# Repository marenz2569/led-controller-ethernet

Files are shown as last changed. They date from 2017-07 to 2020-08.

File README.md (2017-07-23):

# led-controller-ethernet

led-controller-ethernet is the hardware to the [avr-ethernet-licht firmware](https://github.com/marenz2569/avr-ethernet-licht).

Its purpurse is to control ws2812 protocol compatible leds via a [udp protocol](https://chch.it/Fensterbogenbeleuchtung).

In addition to the pcb the hardware uses an arduino pro mini and an enc28j60 breakout board.

## flexibilty

input voltage | output voltage | bridges | notes
--- | --- | --- | ---
12-36V | 12-36V | JP1 |
12-36V | 5V | JP2 |
5V | 5V | JP1 and JP2 | do not populate voltage regulator

## todo
- test if regulator may be populated when inserting 5 Volts to V\_in and bridging JP1 and JP2
- add option for rgb leds with 3 mosfets.

## license
see lgplv2.1 in LICENSE file.

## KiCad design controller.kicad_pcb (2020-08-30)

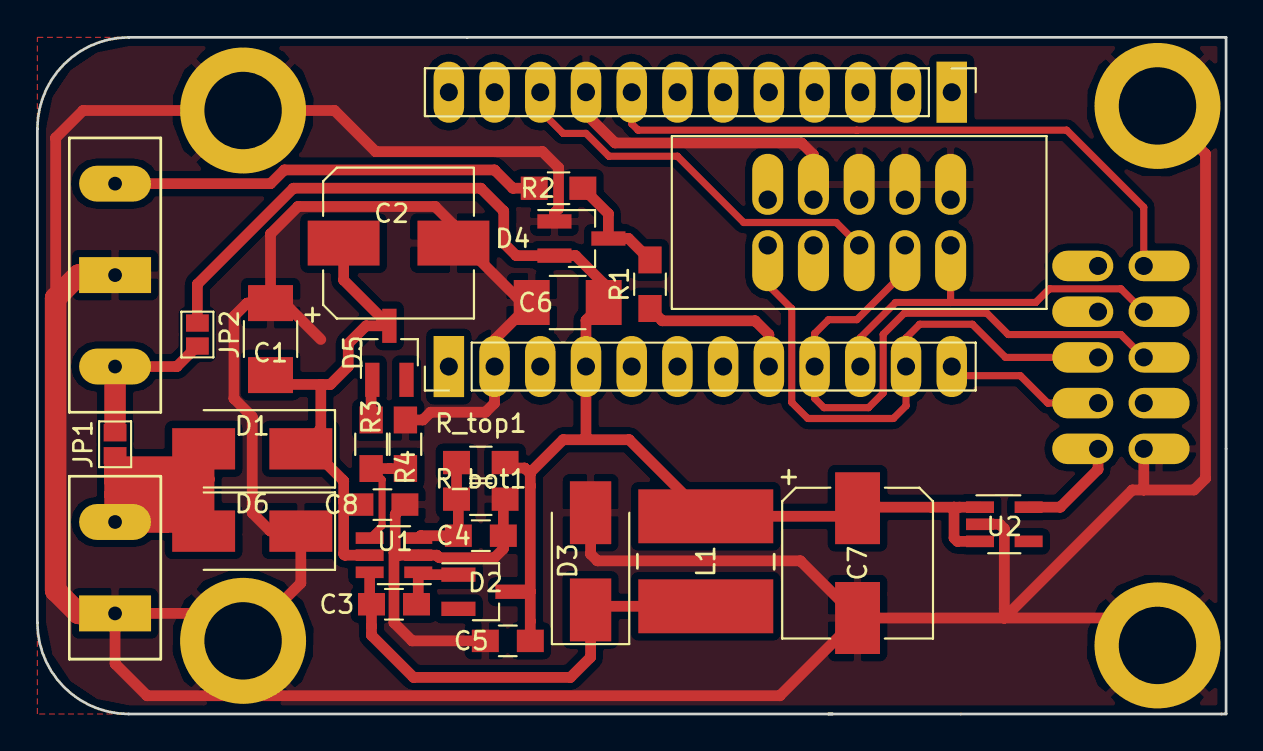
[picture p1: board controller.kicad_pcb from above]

Board: 2 copper layers, 66.0 x 37.6 mm, 35 parts (1 on the bottom side), 20 nets.

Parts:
C1, C6: 10u; C_1210_HandSoldering
C2: 100u; CP_Elec_8x10
C3, C5, C8: 100n; C_0805_HandSoldering
C4: n.b.; C_0805_HandSoldering
C7: 470u; CP_Elec_8x10
CON1: AVR-ISP-10; IDC_Header_Straight_10pins
D1, D3: SS24/SS26; D_SMB_Handsoldering
D2: BAS70-06; SOT-23_Handsoldering
D4: BAV99; SOT-23_Handsoldering
D5: BZX84C 8V2; D_SOT-23_ANK
D6: P6SMB36CA; D_SMB_Handsoldering
JP1: JUMPER; GS2
JP2: JUMPER_NO_Small; GS2
L1: 33u; Choke_SMD_Wuerth-WE-PD2-Typ-L
P1: VIN; 2_5.08mm
P2: LEDOUT; 3_5.08mm
P3, P5: CONN_01X12; Socket_Strip_Straight_1x12_Pitch2.54mm
P4: CONN_02X05; Socket_Strip_Straight_2x05_Pitch2.54mm
P6, P7, P8, P9: CONN_01X01; MountingHole_4.3mm_M4_ISO14580_Pad
R1, R2: 50R; R_0805_HandSoldering
R3, R4: 10k; R_0805_HandSoldering
R_bot1: 8k2; R_0805_HandSoldering
R_top1: 43k; R_0805_HandSoldering
U1: MCP16331; SOT-23-6_Handsoldering
U2: TLV70033DDC; SOT-23-5_HandSoldering

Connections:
+3V3: P4.9, U2.5
+5V: C5.1, C6.1, C7.1, D2.3, D4.2, JP2.1, L1.1, P5.4, R_top1.1, U2.1, U2.3
GND: C1.2, C2.2, C4.2, C5.2, C6.2, C7.2, C8.2, CON1.4, CON1.6, CON1.8, CON1.10, D3.2, D4.1, D6.1, P1.2, P2.2, P3.9, P4.10, P5.2, P6.1, P7.1, P8.1, P9.1, R4.2, R_bot1.2, U1.2, U2.2
INT0: P3.8, P4.2
LEDOUT: P2.1, R2.1
MISO: CON1.9, P4.4, P5.10
MOSI: CON1.1, P4.5, P5.11
unnamed: C1.1, C2.1, C8.1, D1.1, D5.1, U1.5
unnamed: C3.1, D2.1, U1.1
unnamed: C3.2, D3.1, L1.2, U1.6
unnamed: C4.1, R_bot1.1, R_top1.2, U1.3
unnamed: D4.3, R1.2, R2.2
unnamed: D5.2, R3.2
unnamed: R3.1, R4.1, U1.4
OUT: JP1.2, JP2.2, P2.3
PORTC0: P5.8, R1.1
RS: CON1.5, P3.10, P5.3
SCK: CON1.7, P4.6, P5.9
SS: P4.7, P5.12
VIN: D1.2, D6.2, JP1.1, P1.1

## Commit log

2017-07-23 gitignore for kicad project
2017-07-23 added hardware version 1.3-2
    [controller.kicad_pcb, controller.sch]
2017-07-23 V_in starts at 12 Volts
2020-08-30 changed some things, years ago
    [controller.kicad_pcb]
2020-08-30 added solvespace files for case of controller
